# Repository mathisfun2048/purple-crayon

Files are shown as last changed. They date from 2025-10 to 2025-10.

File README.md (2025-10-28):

# STARDUST: Behind the Scenes

Watch the video (https://www.youtube.com/watch?v=CYAAUwyI8sE)

https://www.youtube.com/watch?v=CYAAUwyI8sE

## Meet the Team
Our team consists of Matthew, Luke, Arya, and Andrew. We are all freshmen, and we were so excited going into our first hackathon! None of us are CS, so this weekend was a learning curve for all of us. It was so fun to participate and be able to make a functioning product! We did not assign specific roles; however, Luke refined the CAD design of our case while Matthew, Arya, and Andrew focused on the electronics and embedded system design.

## Exigence
Initially, STARDUST originated from the idea of being able to take notes on any wall or surface. As we developed, we found many more applications for our technology. Rather than something that needs to be restricted to a specific area, STARDUST allows for the display of information in unconventional places. This has applications in unstable environments, where portable announcements or unconventional schooling is needed such as post natural disaster or displacement.

We focused on making the design as simple as possible: with the only input being a force sensor, STARDUST is inherently intuitive. It was definitely a challenge fitting everything into the small form factor, but we are glad we were able to see our vision to completion.

## Challenges & Solutions
Unsurprisingly, the STARDUST came with many challenges and learning opportunities. Thankfully, each one was packaged with incredibly interesting solutions that stuck with us after hours of troubleshooting. We’d like to share some developments that were particularly meaningful to us:

### Electrical
We really wished for the STARDUST to be wireless. However, we didn’t have reliable batteries or a voltage regulator. Ultimately we settled on a pretty funny solution. Deglove a power bank with a dremel and steal the components. To keep the power bank active, we’d constantly drain power from it using an LED (something that became very useful down the line when working with OpenCV).

In the early morning of 2 AM, we had many problems integrating wireless communications into our setup. The combination of our rapidly updating force sensor and frequent bluetooth transmissions would cause current spikes within our entire circuit. These current spikes would consistently create large voltage drops, leading to brownouts and constant loss of communications between our wireless systems. We learned to implement capacitors into our circuit to steady the voltage and prevent brownouts.

### Software
Every movement of the STARDUST pen would slightly misplace our pen’s sensitive force sensor, causing erratic and inconsistent brush strokes. To combat this, instead of setting a constant threshold force to tell the STARDUST when to draw, we created a variable threshold that would adapt to the current state of the force sensor. This variable system averages the force of the sensor when it isn’t drawing, and sets the threshold force (to create brush strokes) above that by a constant. Through this method, we were able to create a system that allowed STARDUST to accurately detect when ADDITIONAL pressure was being applied to the pen, thus prompting it to draw.

### Mechanical
We had issues with the tip of the STARDUST. Since the tip had to be fully disconnected from the rest of the body while still being restricted to the body, a simple cylinder with a semi-sphere set-up will not work, since that will rotate within the body which we cannot have since the actuator inside the tip needs to touch the force sensor. We came up with a CAD revision where a 1.5mm extrusion was added to the middle cylinder and an equal length cut was made from the outer, allowing press and push movement but restricting rotation.

We also encountered issues with packaging. Despite borrowing the compact packaging of a pre-bought power bank, getting loads of electronics and wires all into a slim form factor was still challenging. There were many times we had to resort to dremeling the interior body walls to make room for the Force Sensor Chip and ESP 32 Chip.

## What's next for STARDUST
We’d love to continue finishing up STARDUST. There were many ideas we wanted to add that we just didn’t have time for within this short period.

One such feature was the integration of multiple phones for more accurate and less cumbersome interactions. Having multiple phones connect to a website and share camera data would allow for the speaker to move freely without worry of blocking the computer vision system. Using phones from the audience would be a convenient and efficient way of improving our product’s quality.

Something else we would love to see for STARDUST is an entirely wireless setup. Currently, our projector is borrowed from one of our very generous friends. However, in the future, we hope to find a standalone, rechargeable projector to fully emphasize our position towards convenience. With this change, you wouldn’t even need a power outlet to use STARDUST.





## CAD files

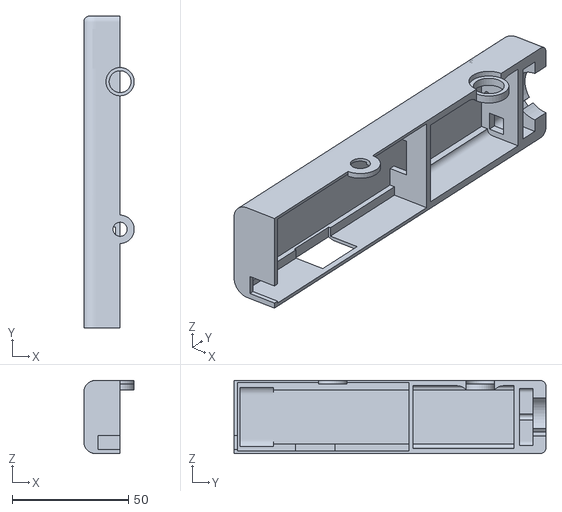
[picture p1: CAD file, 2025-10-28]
penpart2.3.STL
21.7 x 134.2 x 31.5

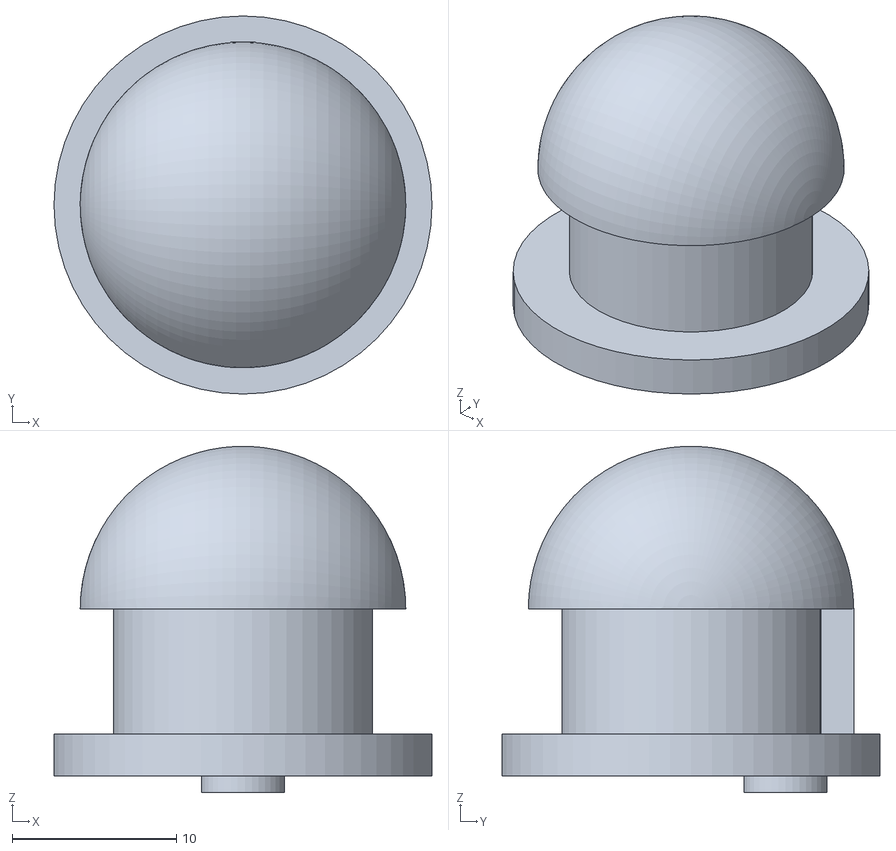
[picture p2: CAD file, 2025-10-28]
penv1.STL
23.0 x 23.0 x 21.1

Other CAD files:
penpart2.1.STL
penpart2.2.STL

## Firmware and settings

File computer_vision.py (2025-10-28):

import cv2
import numpy as np
from collections import deque
import asyncio
from bleak import BleakClient, BleakScanner
import threading
import time
import os  # NEW: For file path validation

# BLE UUIDs - MUST match the ESP32 code
SERVICE_UUID = "4fafc201-1fb5-459e-8fcc-c5c9c331914b"
CHARACTERISTIC_UUID = "beb5483e-36e1-4688-b7f5-ea07361b26a8"

class GreenPixelTracker:
    def __init__(self):
        print("\n" + "="*60)
        print("🎨 PRESSURE-SENSITIVE DRAWING SYSTEM (FAST)")
        print("="*60)

        # ---------- Performance knobs (PC-side) ----------
        self.proc_fps = 15            # Vision processing rate (Hz)  ← lower for less CPU
        self.ui_fps   = 24            # UI refresh rate (Hz)
        self.proc_period_ms = int(1000 / self.proc_fps)
        self.ui_period_ms   = int(1000 / self.ui_fps)
        self.last_proc_ms = 0
        self.last_ui_ms   = 0

        # LED ROI search window (pixels). Small = faster. Expands if target lost.
        self.roi_half_base = 60       # base half-size of ROI box
        self.roi_half      = self.roi_half_base
        self.roi_downscale = 1.0      # 0.5 to speed up more (coords are scaled back)
        self.max_fullframe_checks = 10  # INCREASED: full-frame searches per second when lost

        # Top-K & bright-core gating to limit pixels used for centroid
        self.TOP_K      = 200         # cap pixels used for centroid (fast & stable)
        self.V_BRIGHT   = 150         # INCREASED: V-channel threshold to reduce false positives (was 100)
        self.ERODE_ON   = True        # one erode to shrink bloom
        self.ERODE_K    = np.ones((3,3), np.uint8)
        self.MIN_DETECTION_AREA = 15  # NEW: Minimum pixel count to consider a detection valid

        # ---------- Camera Setup ----------
        camera_index = 1
        print(f"\n📷 Initializing camera...")
        print(f"   Trying camera index {camera_index} (iPhone/External)...")

        self.camera = cv2.VideoCapture(camera_index)
        if not self.camera.isOpened():
            print(f"   ⚠️  Camera {camera_index} not available")
            print(f"   Trying default webcam (index 0)...")
            self.camera = cv2.VideoCapture(0)

        if self.camera.isOpened():
            # Reduce resolution for better performance
            self.camera.set(cv2.CAP_PROP_FRAME_WIDTH,  640)
            self.camera.set(cv2.CAP_PROP_FRAME_HEIGHT, 480)
            # Drop buffering so we don't build a backlog
            try:
                self.camera.set(cv2.CAP_PROP_BUFFERSIZE, 1)
            except Exception:
                pass
            try:
                cv2.setUseOptimized(True)
                cv2.setNumThreads(2)   # tune 1–4 depending on CPU
            except Exception:
                pass
            actual_width  = int(self.camera.get(cv2.CAP_PROP_FRAME_WIDTH))
            actual_height = int(self.camera.get(cv2.CAP_PROP_FRAME_HEIGHT))
            print(f"   ✅ Camera ready: {actual_width}x{actual_height} (performance mode)")
        else:
            print("   ❌ No camera available!")
            exit(1)

        # ---------- ArUco Setup ----------
        print("\n🎯 Setting up ArUco marker detection...")
        self.aruco_dict = cv2.aruco.getPredefinedDictionary(cv2.aruco.DICT_4X4_50)
        self.aruco_params = cv2.aruco.DetectorParameters()
        self.aruco_detector = cv2.aruco.ArucoDetector(self.aruco_dict, self.aruco_params)
        self.transform_matrix = None
        self.marker_size = 200
        self.margin = 40
        self.awaiting_calibration = False  # only detect markers when True
        print("   ✅ ArUco detector initialized")
        print("   Looking for markers: 0, 1, 2, 3")

        # ---------- Canvas Setup ----------
        print("\n🖼️  Creating canvas...")
        self.canvas_size = (720, 1280)
        self.canvas = self._make_fiducial_canvas()
        self.calibration_canvas = self.canvas.copy()
        self.is_calibrated = False
        self.last_draw_point = None
        print(f"   ✅ Canvas created: {self.canvas_size[1]}x{self.canvas_size[0]}")
        print("   ArUco markers placed at corners")

        # ---------- Undo History ----------
        self.canvas_history = deque(maxlen=50)  # Store last 50 states
        self.save_canvas_state()  # Save initial state

        # ---------- Smoothing ----------
        self.position_history = deque(maxlen=5)
        self.last_green_pos_raw = None  # for ROI seeding
        self.last_fullframe_check = 0.0

        # ---------- Color Detection (Green LED) ----------
        print("\n🟢 Configuring GREEN LED tracking (HSV)…")
        self.green_lower = np.array([40, 50, 50])  # H,S,V - Wider green range
        self.green_upper = np.array([80, 255, 255])
        self.min_area = 20  # LEDs are point sources; keep small
        print("   ✅ HSV range configured for green LED")
        print("   ✅ Using H=40-80 (proper green range)")

        # ---------- Drawing Modes ----------
        self.BRUSH_MODE = 0
        self.ERASER_MODE = 1
        self.drawing_mode = self.BRUSH_MODE

        # ========== NEW: COLOR PALETTE ==========
        # Define 5 colors that users can select with keys 1-5
        # Each color is in BGR format (Blue, Green, Red) - that's how OpenCV stores colors
        self.color_palette = {
            1: (255, 255, 255),  # White (B=255, G=255, R=255)
            2: (0, 0, 255),      # Red (B=0, G=0, R=255)
            3: (0, 255, 0),      # Green (B=0, G=255, R=0)
            4: (255, 0, 0),      # Blue (B=255, G=0, R=0)
            5: (0, 255, 255),    # Yellow (B=0, G=255, R=255)
        }
        # Color names for display (matching the keys above)
        self.color_names = {
            1: "White",
            2: "Red", 
            3: "Green",
            4: "Blue",
            5: "Yellow"
        }
        # Start with white color (key 1)
        self.current_color = self.color_palette[1]
        self.current_color_key = 1
        print("\n🎨 Color palette initialized:")
        print("   [1] White  [2] Red  [3] Green  [4] Blue  [5] Yellow")

        # ========== NEW: IMAGE PASTING FEATURE ==========
        # This will store the image that the user wants to paste
        self.paste_image = None
        # This controls the size of the pasted image (you can adjust this)
        self.paste_image_size = 150  # pixels width/height (default)
        self.paste_size_min = 50      # Minimum paste size
        self.paste_size_max = 500     # Maximum paste size
        self.paste_size_step = 25     # How much to change size each time
        print("\n🖼️  Image pasting feature ready")
        print("   Press [I] to enter image file path, then [P] to paste at cursor")
        print(f"   Press [ ] to decrease/increase paste size (current: {self.paste_image_size}px)")

        # ---------- Force Sensor Setup ----------
        print("\n⚡ Force sensor configuration...")
        self.force_value = 0
        
        # AUTO-TUNING THRESHOLD SYSTEM
        self.force_history = deque(maxlen=150)  # Track last ~10 seconds at 15fps
        self.baseline_percentile = 30  # Use 30th percentile as baseline (robust to peaks)
        self.sensitivity_margin = 80  # How much above baseline = drawing (adjustable with +/-)
        self.force_threshold = 280  # Initial value, will auto-adjust
        self.auto_tune_enabled = True  # Toggle with 'a' key
        
        self.min_thickness = 1
        self.max_thickness = 30  # DOUBLED from 15 to 30 for more sensitivity
        self.eraser_multiplier = 2.5  # Eraser is 2.5x larger than brush
        self.force_max = 1024
        self.sensor_max_newtons = 1.0
        print(f"   🤖 AUTO-TUNING ENABLED: Threshold adapts to sensor drift")
        print(f"   Initial sensitivity margin: {self.sensitivity_margin} ADC above baseline")
        print(f"   Eraser size: {self.eraser_multiplier}x brush size")

        # ---------- BLE ----------
        self.ble_client = None
        self.ble_connected = False
        self.running = True
        self.last_data_received = 0
        self.device_address = None   # cache address to skip scans

        print("\n🚀 Starting BLE connection thread…")
        self.ble_thread = threading.Thread(target=self.run_ble_loop, daemon=True)
        self.ble_thread.start()

        print("\n" + "="*60)
        print("✅ SYSTEM READY")
        print("="*60)
        print("⌨️  Calibration: [C]alibrate")
        print("⌨️  Drawing: [B]rush | [E]raser | [X]Clear | [U]ndo")
        print("⌨️  Colors: [1]White [2]Red [3]Green [4]Blue [5]Yellow")
        print("⌨️  Images: [I]Enter image path | [P]aste at cursor | [ ]Size-/+")
        print("⌨️  Settings: [+/-]Sensitivity | [A]uto-tune | [R]eset")
        print("⌨️  Debug: [M]ask | [T]HSV tuner | [,/.]Brightness | [Q]uit")
        print("="*60 + "\n")

    # ----------------------------------------------------------------
    # NEW: Image Loading and Pasting Functions
    # ----------------------------------------------------------------
    def change_paste_size(self, increase=True):
        """
        Change the size of pasted images.
        If an image is already loaded, it will be re-resized.
        
        increase: True to increase size, False to decrease
        """
        old_size = self.paste_image_size
        
        if increase:
            # Increase size (up to maximum)
            self.paste_image_size = min(self.paste_size_max, 
                                       self.paste_image_size + self.paste_size_step)
        else:
            # Decrease size (down to minimum)
            self.paste_image_size = max(self.paste_size_min, 
                                       self.paste_image_size - self.paste_size_step)
        
        # Check if size actually changed
        if old_size == self.paste_image_size:
            if increase:
                print(f"⚠️  Maximum paste size reached: {self.paste_size_max}px")
            else:
                print(f"⚠️  Minimum paste size reached: {self.paste_size_min}px")
            return
        
        # Print new size
        direction = "increased" if increase else "decreased"
        print(f"📏 Paste size {direction}: {self.paste_image_size}px (was {old_size}px)")
        
        # If an image is already loaded, re-resize it to the new size
        if self.paste_image is not None:
            # If we have the original image, resize from that (better quality)
            if hasattr(self, 'original_paste_image'):
                self.paste_image = cv2.resize(self.original_paste_image, 
                                             (self.paste_image_size, self.paste_image_size))
                print(f"   ✅ Loaded image resized to {self.paste_image_size}x{self.paste_image_size}")
            else:
                # No original, resize from current (may lose quality)
                self.paste_image = cv2.resize(self.paste_image, 
                                             (self.paste_image_size, self.paste_image_size))
                print(f"   ⚠️  Image resized (may have quality loss)")
                print("   Tip: Reload with [I] for best quality at this size")
    
    def load_image(self):
        """
        Prompts user to enter an image file path via terminal.
        The image is loaded and stored in self.paste_image.
        """
        print("\n" + "="*60)
        print("📂 LOAD IMAGE")
        print("="*60)
        print("Enter the full path to your image file.")
        print("TIP: You can drag and drop the file into the terminal!")
        print("Example: /Users/yourname/Pictures/image.png")
        print("Press Enter without typing anything to cancel.")
        print("="*60)
        
        # Get file path from user
        file_path = input("Image path: ").strip()
        
        # Remove quotes if user copy-pasted with quotes
        file_path = file_path.strip('"').strip("'")
        
        # Check if user cancelled
        if not file_path:
            print("⚠️  Cancelled - no file path entered")
            return
        
        # Check if file exists
        if not os.path.exists(file_path):
            print(f"❌ File not found: {file_path}")
            print("   Make sure the path is correct and try again")
            return
        
        # Try to load the image using OpenCV
        img = cv2.imread(file_path)
        
        if img is not None:
            # Image loaded successfully!
            # Store the original image so we can re-resize it later without quality loss
            self.original_paste_image = img.copy()
            
            # Resize it to our standard paste size for consistency
            # cv2.resize changes the image dimensions
            self.paste_image = cv2.resize(img, (self.paste_image_size, self.paste_image_size))
            print(f"✅ Image loaded successfully!")
            print(f"   Resized to {self.paste_image_size}x{self.paste_image_size} pixels")
            print("   Press [P] when cursor is where you want to paste")
            print("   Press [ or ] to change paste size")
        else:
            print(f"❌ Failed to load image: {file_path}")
            print("   Make sure it's a valid image file (PNG, JPG, etc.)")
        
        print("="*60 + "\n")
    
    def paste_image_at_cursor(self, cursor_pos):
        """
        Pastes the loaded image onto the canvas at the cursor position.
        The image is centered on the cursor.
        
        cursor_pos: (x, y) tuple of where to paste the image
        """
        # Check if we have an image to paste
        if self.paste_image is None:
            print("⚠️  No image loaded! Press [I] to load an image first")
            return
        
        # Check if we're calibrated (we need the transform to work)
        if not self.is_calibrated:
            print("⚠️  Please calibrate first (press [C])")
            return
        
        # Save canvas state for undo functionality
        self.save_canvas_state()
        
        # Get the image dimensions
        img_h, img_w = self.paste_image.shape[:2]
        
        # Calculate top-left corner position to center the image on cursor
        # We subtract half the width and height to center it
        x = cursor_pos[0] - img_w // 2  # // means integer division
        y = cursor_pos[1] - img_h // 2
        
        # Calculate bottom-right corner
        x_end = x + img_w
        y_end = y + img_h
        
        # Make sure we don't paste outside the canvas bounds
        # We need to clip the coordinates to stay within canvas
        
        # Clipping for canvas boundaries
        canvas_h, canvas_w = self.canvas.shape[:2]
        
        # Calculate how much of the image fits in the canvas
        # If image goes off-screen, we only paste the visible part
        src_x_start = max(0, -x)  # If x is negative, start from this pixel in source image
        src_y_start = max(0, -y)  # If y is negative, start from this pixel in source image
        src_x_end = img_w - max(0, x_end - canvas_w)  # If goes past right edge
        src_y_end = img_h - max(0, y_end - canvas_h)  # If goes past bottom edge
        
        # Adjust paste position to canvas bounds
        dst_x_start = max(0, x)
        dst_y_start = max(0, y)
        dst_x_end = min(canvas_w, x_end)
        dst_y_end = min(canvas_h, y_end)
        
        # Extract the portion of image that fits
        img_portion = self.paste_image[src_y_start:src_y_end, src_x_start:src_x_end]
        
        # Paste the image onto the canvas
        # We directly copy the pixels from the image to the canvas
        try:
            self.canvas[dst_y_start:dst_y_end, dst_x_start:dst_x_end] = img_portion
            print(f"✅ Image pasted at ({cursor_pos[0]}, {cursor_pos[1]})")
        except Exception as e:
            print(f"❌ Error pasting image: {e}")

    # ----------------------------------------------------------------
    # HSV Tuner for finding exact color values
    # ----------------------------------------------------------------
    def test_color_range(self):
        """Interactive HSV tuner - adjust sliders to find your LED's exact color"""
        print("\n" + "="*60)
        print("🎨 HSV COLOR TUNER")
        print("="*60)
        print("Adjust sliders until your LED appears WHITE in the mask window")
        print("Press 'p' to print current values")
        print("Press 'q' to quit tuner")
        print("="*60 + "\n")
        
        cv2.namedWindow("HSV Tuner - Mask")
        cv2.namedWindow("HSV Tuner - Original")
        
        # Create sliders with current values as defaults
        cv2.createTrackbar("H Low", "HSV Tuner - Mask", 40, 179, lambda x: None)
        cv2.createTrackbar("H High", "HSV Tuner - Mask", 80, 179, lambda x: None)
        cv2.createTrackbar("S Low", "HSV Tuner - Mask", 50, 255, lambda x: None)
        cv2.createTrackbar("S High", "HSV Tuner - Mask", 255, 255, lambda x: None)
        cv2.createTrackbar("V Low", "HSV Tuner - Mask", 50, 255, lambda x: None)
        cv2.createTrackbar("V High", "HSV Tuner - Mask", 255, 255, lambda x: None)
        
        while True:
            ret, frame = self.camera.read()
            if not ret:
                break
            
            # Get slider values
            h_low = cv2.getTrackbarPos("H Low", "HSV Tuner - Mask")
            h_high = cv2.getTrackbarPos("H High", "HSV Tuner - Mask")
            s_low = cv2.getTrackbarPos("S Low", "HSV Tuner - Mask")
            s_high = cv2.getTrackbarPos("S High", "HSV Tuner - Mask")
            v_low = cv2.getTrackbarPos("V Low", "HSV Tuner - Mask")
            v_high = cv2.getTrackbarPos("V High", "HSV Tuner - Mask")
            
            # Create mask with current settings
            hsv = cv2.cvtColor(frame, cv2.COLOR_BGR2HSV)
            lower = np.array([h_low, s_low, v_low])
            upper = np.array([h_high, s_high, v_high])
            mask = cv2.inRange(hsv, lower, upper)
            
            # Add text overlay with current values
            mask_display = cv2.cvtColor(mask, cv2.COLOR_GRAY2BGR)
            cv2.putText(mask_display, f"H: {h_low}-{h_high}", (10, 30),
                       cv2.FONT_HERSHEY_SIMPLEX, 0.7, (0, 255, 0), 2)
            cv2.putText(mask_display, f"S: {s_low}-{s_high}", (10, 60),
                       cv2.FONT_HERSHEY_SIMPLEX, 0.7, (0, 255, 0), 2)
            cv2.putText(mask_display, f"V: {v_low}-{v_high}", (10, 90),
                       cv2.FONT_HERSHEY_SIMPLEX, 0.7, (0, 255, 0), 2)
            cv2.putText(mask_display, "Press 'p' to print values", (10, 450),
                       cv2.FONT_HERSHEY_SIMPLEX, 0.6, (0, 255, 255), 2)
            
            # Show windows
            cv2.imshow("HSV Tuner - Mask", mask_display)
            cv2.imshow("HSV Tuner - Original", frame)
            
            key = cv2.waitKey(1) & 0xFF
            if key == ord('p'):
                print("\n" + "="*60)
                print("📋 CURRENT HSV VALUES:")
                print("="*60)
                print(f"self.green_lower = np.array([{h_low}, {s_low}, {v_low}])")
                print(f"self.green_upper = np.array([{h_high}, {s_high}, {v_high}])")
                print("="*60 + "\n")
            elif key == ord('q'):
                break
        
        cv2.destroyWindow("HSV Tuner - Mask")
        cv2.destroyWindow("HSV Tuner - Original")
        print("✅ HSV Tuner closed\n")

    # ----------------------------------------------------------------
    # BLE Functions
    # ----------------------------------------------------------------
    def run_ble_loop(self):
        loop = asyncio.new_event_loop()
        asyncio.set_event_loop(loop)
        loop.run_until_complete(self.connect_ble())
        loop.close()

    async def fast_find_device(self, name_substring="ForceStylus", timeout=0.25):
        """Quickly find by name; returns device or None."""
        try:
            device = await BleakScanner.find_device_by_filter(
                lambda d, ad: (d.name and name_substring in d.name), timeout=timeout
            )
            return device
        except Exception:
            devices = await BleakScanner.discover(timeout=timeout)
            for d in devices:
                if d.name and name_substring in d.name:
                    return d
            return None

    def _on_disconnect(self, client):
        print("\n🔌 BLE disconnected (callback).")
        self.ble_connected = False

    async def connect_ble(self):
        """Find and connect to the ESP32 via BLE with very fast auto-reconnect"""
        backoff = 0.2  # quick retry

        while self.running:
            print("\n" + "="*60)
            print("🔍 SCANNING/CONNECTING BLUETOOTH (FAST)")
            print("="*60)

            try:
                device = None
                if self.device_address:
                    print(f"   Using cached address: {self.device_address}")
                    device = type("Tmp", (), {"address": self.device_address})()
                else:
                    print("   Fast find 'ForceStylus'… (≤0.25s)")
                    device = await self.fast_find_device("ForceStylus", timeout=0.25)

                if not device:
                    print("   ❌ Not found. Quick retry…")
                    await asyncio.sleep(backoff)
                    continue

                address = device.address if hasattr(device, "address") else device
                print(f"\n🔗 Connecting to {address} …")
                async with BleakClient(address, disconnected_callback=self._on_disconnect, timeout=3.0) as client:
                    self.ble_client = client
                    self.ble_connected = True
                    if not self.device_address:
                        self.device_address = address  # cache for next time
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

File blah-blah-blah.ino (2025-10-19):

/*
 * ESP32 Xiao S3 - SingleTact 1N Force Sensor via BLE
 * FIXED VERSION - Stable BLE with proper task separation
 * 
 * Wiring (Xiao ESP32 S3):
 *   SingleTact VCC → 3.3V
 *   SingleTact GND → GND
 *   SingleTact SDA → GPIO 5 (D4)
 *   SingleTact SCL → GPIO 6 (D5)
 */

#include <Wire.h>
#include <BLEDevice.h>
#include <BLEServer.h>
#include <BLEUtils.h>
#include <BLE2902.h>

// SingleTact Configuration
const uint8_t SENSOR_ADDRESS = 0x04;
const int SDA_PIN = 5;
const int SCL_PIN = 6;

// SingleTact 1N Sensor Specs
const float SENSOR_MAX_FORCE = 1.0;   // 1 Newton max
const int SENSOR_MAX_VALUE = 1024;    // Raw value range 0-1024

// BLE UUIDs
#define SERVICE_UUID        "4fafc201-1fb5-459e-8fcc-c5c9c331914b"
#define CHARACTERISTIC_UUID "beb5483e-36e1-4688-b7f5-ea07361b26a8"

// Global variables
BLECharacteristic *pCharacteristic;
BLEServer *pServer;
volatile bool deviceConnected = false;
volatile bool oldDeviceConnected = false;
bool sensorDetected = false;

// Sensor data (thread-safe access)
SemaphoreHandle_t dataMutex;
volatile int currentRawValue = 0;
volatile bool newDataAvailable = false;

// Task handles
TaskHandle_t sensorTaskHandle = NULL;
TaskHandle_t bleTaskHandle = NULL;

class ServerCallbacks: public BLEServerCallbacks {
  void onConnect(BLEServer* pServer) {
    deviceConnected = true;
    Serial.println("\n✅ BLE CLIENT CONNECTED!");
    
    // Request connection parameter update for stability
    // Min interval: 7.5ms, Max interval: 20ms, Latency: 0, Timeout: 400ms
    pServer->updateConnParams(0, 6, 16, 0, 400);
  }
  
  void onDisconnect(BLEServer* pServer) {
    deviceConnected = false;
    Serial.println("\n❌ BLE CLIENT DISCONNECTED");
  }
};

// I2C communication with sensor (runs in separate task)
int readSingleTactNonBlocking() {
  // Send command
  Wire.beginTransmission(SENSOR_ADDRESS);
  Wire.write(0x00);
  if (Wire.endTransmission() != 0) {
    return -1;
  }
  
  // Use vTaskDelay instead of delay for proper FreeRTOS timing
  vTaskDelay(pdMS_TO_TICKS(5));
  
  // Request data with timeout
  Wire.requestFrom(SENSOR_ADDRESS, 6);
  
  unsigned long timeout = millis() + 10;
  while (Wire.available() < 6 && millis() < timeout) {
    vTaskDelay(pdMS_TO_TICKS(1));
  }
  
  if (Wire.available() >= 6) {
    byte data[6];
    for (int i = 0; i < 6; i++) {
      data[i] = Wire.read();
    }
    return (data[4] << 8) | data[5];
  }
  
  return -1;
}

// Task 1: Handle sensor reading (Core 0)
void sensorTask(void *pvParameters) {
  Serial.println("Sensor task started on core 0");
  
  while (1) {
    if (sensorDetected) {
      int raw = readSingleTactNonBlocking();
      
      if (raw >= 0) {
        // Update shared data with mutex protection
        if (xSemaphoreTake(dataMutex, pdMS_TO_TICKS(10)) == pdTRUE) {
          currentRawValue = raw;
          newDataAvailable = true;
          xSemaphoreGive(dataMutex);
        }
      }
      
      // Sensor read rate: 20Hz (50ms)
      vTaskDelay(pdMS_TO_TICKS(50));
    } else {
      // Test mode - generate dummy data
      static int testVal = 0;
      testVal = (testVal + 10) % 1024;
      
      if (xSemaphoreTake(dataMutex, pdMS_TO_TICKS(10)) == pdTRUE) {
        currentRawValue = testVal;
        newDataAvailable = true;
        xSemaphoreGive(dataMutex);
      }
      
      vTaskDelay(pdMS_TO_TICKS(100));
    }
    
    // Feed watchdog
    esp_task_wdt_reset();
  }
}

// Task 2: Handle BLE communication (Core 1)
void bleTask(void *pvParameters) {
  Serial.println("BLE task started on core 1");
  
  while (1) {
    // Handle connection state changes
    if (deviceConnected != oldDeviceConnected) {
      if (!deviceConnected && oldDeviceConnected) {
        vTaskDelay(pdMS_TO_TICKS(500));
        pServer->startAdvertising();
        Serial.println("Restarted advertising");
      }
      oldDeviceConnected = deviceConnected;
    }
    
    // Send data if connected and new data available
    if (deviceConnected && newDataAvailable) {
      if (xSemaphoreTake(dataMutex, pdMS_TO_TICKS(10)) == pdTRUE) {
        int value = currentRawValue;
        newDataAvailable = false;
        xSemaphoreGive(dataMutex);
        
        // Send via BLE
        uint8_t data[2] = {value & 0xFF, (value >> 8) & 0xFF};
        pCharacteristic->setValue(data, 2);
        pCharacteristic->notify();
        
        // Optional: Print for debugging
        static unsigned long lastPrint = 0;
        if (millis() - lastPrint > 1000) {
          float force = (value / (float)SENSOR_MAX_VALUE) * SENSOR_MAX_FORCE;
          Serial.print("Force: ");
          Serial.print(force, 3);
          Serial.println(" N");
          lastPrint = millis();
        }
      }
    }
    
    // BLE task rate: 10ms (allows quick response to notifications)
    vTaskDelay(pdMS_TO_TICKS(10));
    
    // Feed watchdog
    esp_task_wdt_reset();
  }
}

void scanI2C() {
  Serial.println("Scanning I2C bus...");
  
  for (byte addr = 1; addr < 127; addr++) {
    Wire.beginTransmission(addr);
    byte error = Wire.endTransmission();
    
    if (error == 0) {
      Serial.print("Found device at 0x");
      if (addr < 16) Serial.print("0");
      Serial.print(addr, HEX);
      if (addr == 0x04) {
        Serial.print(" ← SingleTact Sensor!");
        sensorDetected = true;
      }
      Serial.println();
    }
  }
}
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

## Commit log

2025-10-18 update force sensor
2025-10-18 I2C scanner
2025-10-18 added force sensor for arduino
2025-10-19 Migrate Python WebSocket and sensor logic to C++
    Converted Python code for WebSocket video capture and force sensor logic to C++ for ESP32. Added BLE functionality and improved task separation for stability.
    [blah-blah-blah.ino]
2025-10-19 Adjust HSV bounds for blue LED detection
    Updated HSV range for blue LED tracking.
2025-10-19 StarDust 3dp CADs
    penv1 - pen tip cad with force sensor actuator
    penpart2.2 - scrapped version of right side
    penpart2.3 - final version of right side
    penpart2.1 - final version of left side
    [penpart2.1.STL, penpart2.2.STL, penpart2.3.STL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]
